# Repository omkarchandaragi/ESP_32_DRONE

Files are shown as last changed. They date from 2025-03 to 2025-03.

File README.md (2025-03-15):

# ESP_32_DRONE
WIFI Controlled Drone
Features of our DIY WiFi-Controlled Drone:
✅WiFi controlled: This can be controlled using a smartphone.
✅MPU6050 IMU for stability control.
✅All-in-one PCB:  Doesn’t need any 3D printed parts or such.
✅Easily upgradable: Additional features such as position hold or height hold can be added using external modules.
✅Small size and lightweight.
✅Built-in battery charger.
✅Built-in USB interface for programming and debugging.
✅Android and IOS apps.
✅Open source

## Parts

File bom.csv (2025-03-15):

Designator | Footprint | Quantity | Value | LCSC Part #
C1, C4 | 603 | 2 | 10u
C10, C15, C16, C17, C18, C8 | 603 | 6 | 1uf
C11, C12, C13, C6 | 603 | 4 | 0.1uf
C14, C5, C7, C9 | 603 | 4 | 10uf
C2 | 603 | 1 | 470pF
C3 | 805 | 1 | 2.2uF
D1 | D_SMA | 1 | SS34
D2, D3, D4, D5 | D_SOD-323 | 4 | 1N4148W
IC1 | SOIC127P600X175-9N | 1 | TP4056
J1 | USB_C_Receptacle_HRO_TYPE-C-31-M-12 | 1 | USB_C_Receptacle_USB2.0
J2, J4, J5, J6 | JST_GH_SM02B-GHS-TB_1x02-1MP_P1.25mm_Horizontal | 4 | Conn_01x02_Female
J3 | JST_PH_B2B-PH-SM4-TB_1x02-1MP_P2.00mm_Vertical | 1 | B2B-PH-SM4-TB(LF)(SN)
J8, J9 | PinHeader_1x06_P2.54mm_Vertical | 2 | Conn_01x06_Female
LED1 | 603 | 1 | POW_LED
LED2, LED3 | 603 | 2 | CHG
LED4, LED5, LED6 | 603 | 3 | LED
R1 | 603 | 1 | 470R
R10, R11, R12, R14, R18, R19, R20, R21, R7 | 603 | 9 | 10k
R13 | 603 | 1 | 4.7k
R15, R16, R17, R8, R9 | 603 | 5 | 1K
R2, U1, U4, U5 | 603 | 4 | 100K
R3, R4 | 603 | 2 | 1.3K
R5 | 603 | 1 | 47.5k
R6 | 603 | 1 | 22.1k
Rprog1 | 603 | 1 | 3.3K
SW1 | slide switch spdt | 1 | K3-1280S-F1
T1, T2, T3, T4 | SOT95P237X112-3N | 4 | SI2302DS-T1
U2 | SOT-23 | 1 | AO3401
U3 | SOT-23-5 | 1 | MIC5219-3.3YM5
U6 | QFN-28-1EP_5x5mm_P0.5mm_EP3.35x3.35mm | 1 | CP2102N-Axx-xQFN28
U7 | SOT-363_SC-70-6 | 1 | 2N7002D
U8 | ESP32-WROOM-32 | 1 | ESP32-WROOM-32
U9 | MPU6050 | 1 | MPU-6050

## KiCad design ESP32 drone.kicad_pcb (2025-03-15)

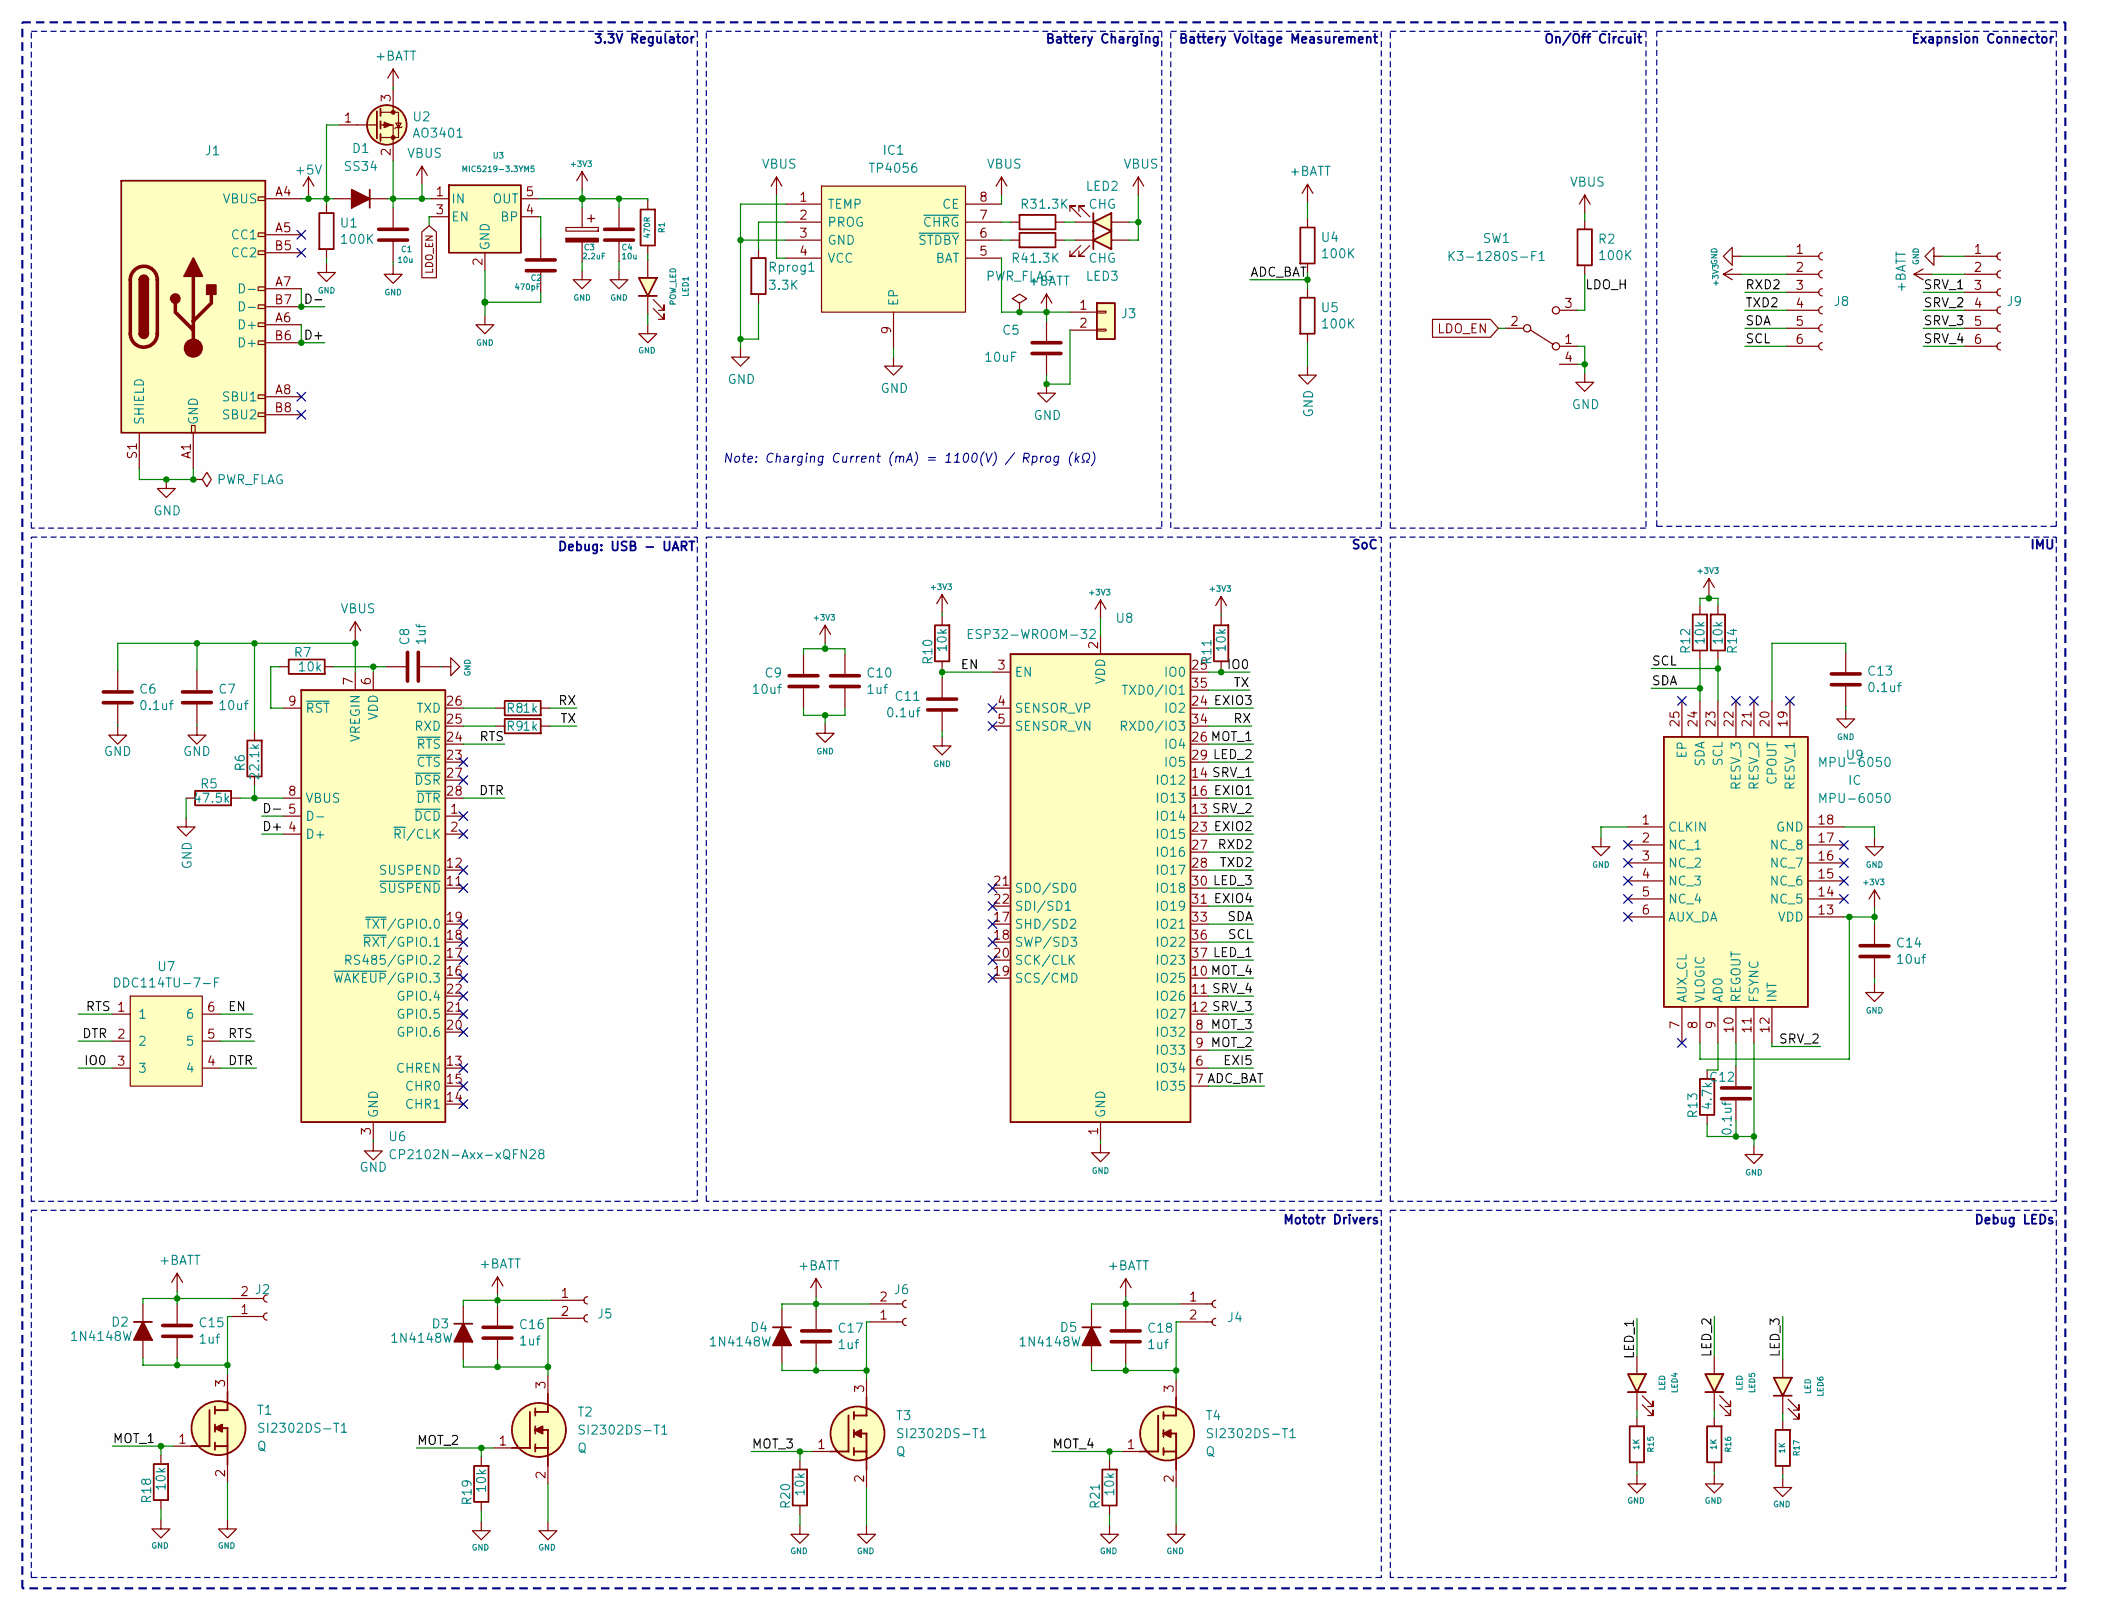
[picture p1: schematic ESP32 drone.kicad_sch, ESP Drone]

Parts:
C1, C4: 10u; C_0603_1608Metric
C2: 470pF; C_0603_1608Metric
C3: 2.2uF; C_0805_2012Metric
C5: 10uF; C_0603_1608Metric
C6, C11, C12, C13: 0.1uf; C_0603_1608Metric
C7, C9, C14: 10uf; C_0603_1608Metric
C8, C10, C15, C16, C17, C18: 1uf; C_0603_1608Metric
D1: SS34; D_SMA
D2, D3, D4, D5: 1N4148W; D_SOD-323
IC1: TP4056; SOIC127P600X175-9N; Manufacturer_Part_Number TP4056-42-ESOP8
J1: USB_C_Receptacle_USB2.0; USB_C_Receptacle_HRO_TYPE-C-31-M-12
J2, J4, J5, J6: Conn_01x02_Female; JST_GH_SM02B-GHS-TB_1x02-1MP_P1.25mm_Horizontal
J3: B2B-PH-SM4-TB(LF)(SN); JST_PH_B2B-PH-SM4-TB_1x02-1MP_P2.00mm_Vertical
J8, J9: Conn_01x06_Female; PinHeader_1x06_P2.54mm_Vertical
LED1: POW_LED; LED_0603_1608Metric
LED2, LED3: CHG; LED_0603_1608Metric
LED4, LED5, LED6: LED; LED_0603_1608Metric
R1: 470R; R_0603_1608Metric
R2: 100K; R_0603_1608Metric
R3, R4: 1.3K; R_0603_1608Metric
R5: 47.5k; R_0603_1608Metric
R6: 22.1k; R_0603_1608Metric
R7, R10, R11, R12, R14, R18, R19, R20, R21: 10k; R_0603_1608Metric
R8, R9: 1k; R_0603_1608Metric
R13: 4.7k; R_0603_1608Metric
R15, R16, R17: 1K; R_0603_1608Metric
Rprog1: 3.3K; R_0603_1608Metric
SW1: K3-1280S-F1; slide switch spdt
T1, T2, T3, T4: SI2302DS-T1; SOT95P237X112-3N; Mouser Part Number 781-SI2302DS
U1, U4, U5: 100K; R_0603_1608Metric
U2: AO3401; SOT-23
U3: MIC5219-3.3YM5; SOT-23-5
U6: CP2102N-Axx-xQFN28; QFN-28-1EP_5x5mm_P0.5mm_EP3.35x3.35mm
U7: DDC114TU-7-F; SOT-363_SC-70-6
U8: ESP32-WROOM-32
U9: MPU-6050; MPU6050; Mouser Part Number 410-MPU-6050

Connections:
+3V3: C3.1, C4.1, C9.1, C10.1, C14.1, J8.2, R1.2, R10.2, R11.2, R12.2, R14.2, U3.5 (OUT), U8.2 (VDD), U9.8 (VLOGIC), U9.13 (VDD)
+5V: D1.2 (A), J1.A4 (VBUS), J1.A9 (VBUS), J1.B4 (VBUS), J1.B9 (VBUS), U1.1, U2.1 (G)
+BATT: C5.1, C15.1, C16.1, C17.1, C18.1, D2.1 (K), D3.1 (K), D4.1 (K), D5.1 (K), IC1.5 (BAT), J2.2, J3.1, J4.1, J5.1, J6.2, J9.2, U2.3 (D), U4.1
/ADC_BAT: U4.2, U5.1, U8.7 (IO35)
/D+: J1.A6 (D+), J1.B6 (D+), U6.4 (D+)
/D-: J1.A7 (D-), J1.B7 (D-), U6.5 (D-)
/DTR: U6.28 (~DTR), U7.2, U7.4
/EN: C11.1, R10.1, U7.6, U8.3 (EN)
/EXI5: U8.6 (IO34)
/EXIO1: U8.16 (IO13)
/EXIO2: U8.23 (IO15)
/EXIO3: U8.24 (IO2)
/EXIO4: U8.31 (IO19)
/IO0: R11.1, U7.3, U8.25 (IO0)
/LDO_H: R2.2, SW1.3 (C)
/LED_1: LED4.2 (A), U8.37 (IO23)
/LED_2: LED5.2 (A), U8.29 (IO5)
/LED_3: LED6.2 (A), U8.30 (IO18)
/MOT_1: R18.2, T1.1 (G), U8.26 (IO4)
/MOT_2: R19.2, T2.1 (G), U8.9 (IO33)
/MOT_3: R20.2, T3.1 (G), U8.8 (IO32)
/MOT_4: R21.2, T4.1 (G), U8.10 (IO25)
/RTS: U6.24 (~RTS), U7.1, U7.5
/RX: R8.2, U8.34 (RXD0/IO3)
/RXD2: J8.3, U8.27 (IO16)
/SCL: J8.6, R14.1, U8.36 (IO22), U9.23 (SCL)
/SDA: J8.5, R12.1, U8.33 (IO21), U9.24 (SDA)
/SRV_1: J9.3, U8.14 (IO12)
/SRV_2: J9.4, U8.13 (IO14), U9.12 (INT)
/SRV_3: J9.5, U8.12 (IO27)
/SRV_4: J9.6, U8.11 (IO26)
/TX: R9.2, U8.35 (TXD0/IO1)
/TXD2: J8.4, U8.28 (IO17)
GND: C1.2, C2.2, C3.2, C4.2, C5.2, C6.2, C7.2, C8.2, C9.2, C10.2, C11.2, C12.2, C13.2, C14.2, IC1.1 (TEMP), IC1.3 (GND), IC1.9 (EP), J1.A1 (GND), J1.A12 (GND), J1.B1 (GND), J1.B12 (GND), J1.S1 (SHIELD), J3.2, J8.1, J9.1, LED1.1 (K), R5.1, R13.1, R15.1, R16.1, R17.1, R18.1, R19.1, R20.1, R21.1, Rprog1.2, SW1.1 (A), SW1.4, T1.2 (S), T2.2 (S), T3.2 (S), T4.2 (S), U1.2, U3.2 (GND), U5.2, U6.3 (GND), U6.29 (GND), U8.1 (GND), U8.15 (GND), U8.38 (GND), U8.39 (GND), U9.1 (CLKIN), U9.11 (FSYNC), U9.18 (GND)
LDO_EN: SW1.2 (B), U3.3 (EN)
unnamed: C15.2, D2.2 (A), J2.1, T1.3 (D)
unnamed: C16.2, D3.2 (A), J5.2, T2.3 (D)
unnamed: C17.2, D4.2 (A), J6.1, T3.3 (D)
unnamed: C18.2, D5.2 (A), J4.2, T4.3 (D)
unnamed: IC1.2 (PROG), Rprog1.1
unnamed: IC1.7 (~CHRG), R3.2
unnamed: IC1.6 (~STDBY), R4.2
unnamed: LED1.2 (A), R1.1
unnamed: LED2.1 (K), R3.1
unnamed: LED3.1 (K), R4.1
unnamed: LED4.1 (K), R15.2
unnamed: LED5.1 (K), R16.2
unnamed: LED6.1 (K), R17.2
unnamed: C2.1, U3.4 (BP)
unnamed: R9.1, U6.25 (RXD)
unnamed: R8.1, U6.26 (TXD)
unnamed: R5.2, R6.1, U6.8 (VBUS)
unnamed: C8.1, R7.2, U6.6 (VDD)
unnamed: R7.1, U6.9 (~RST)
unnamed: R13.2, U9.9 (AD0)
unnamed: C13.1, U9.20 (CPOUT)
unnamed: C12.1, U9.10 (REGOUT)
VBUS: C1.1, C6.1, C7.1, D1.1 (K), IC1.4 (VCC), IC1.8 (CE), LED2.2 (A), LED3.2 (A), R2.1, R6.2, U2.2 (S), U3.1 (IN), U6.7 (VREGIN)

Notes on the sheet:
SoC
Battery Voltage Measurement
IMU
Mototr Drivers
Battery Charging
Debug LEDs
Debug: USB - UART
Exapnsion Connector
3.3V Regulator
Note: Charging Current (mA) = 1100(V) / Rprog (kΩ)
On/Off Circuit

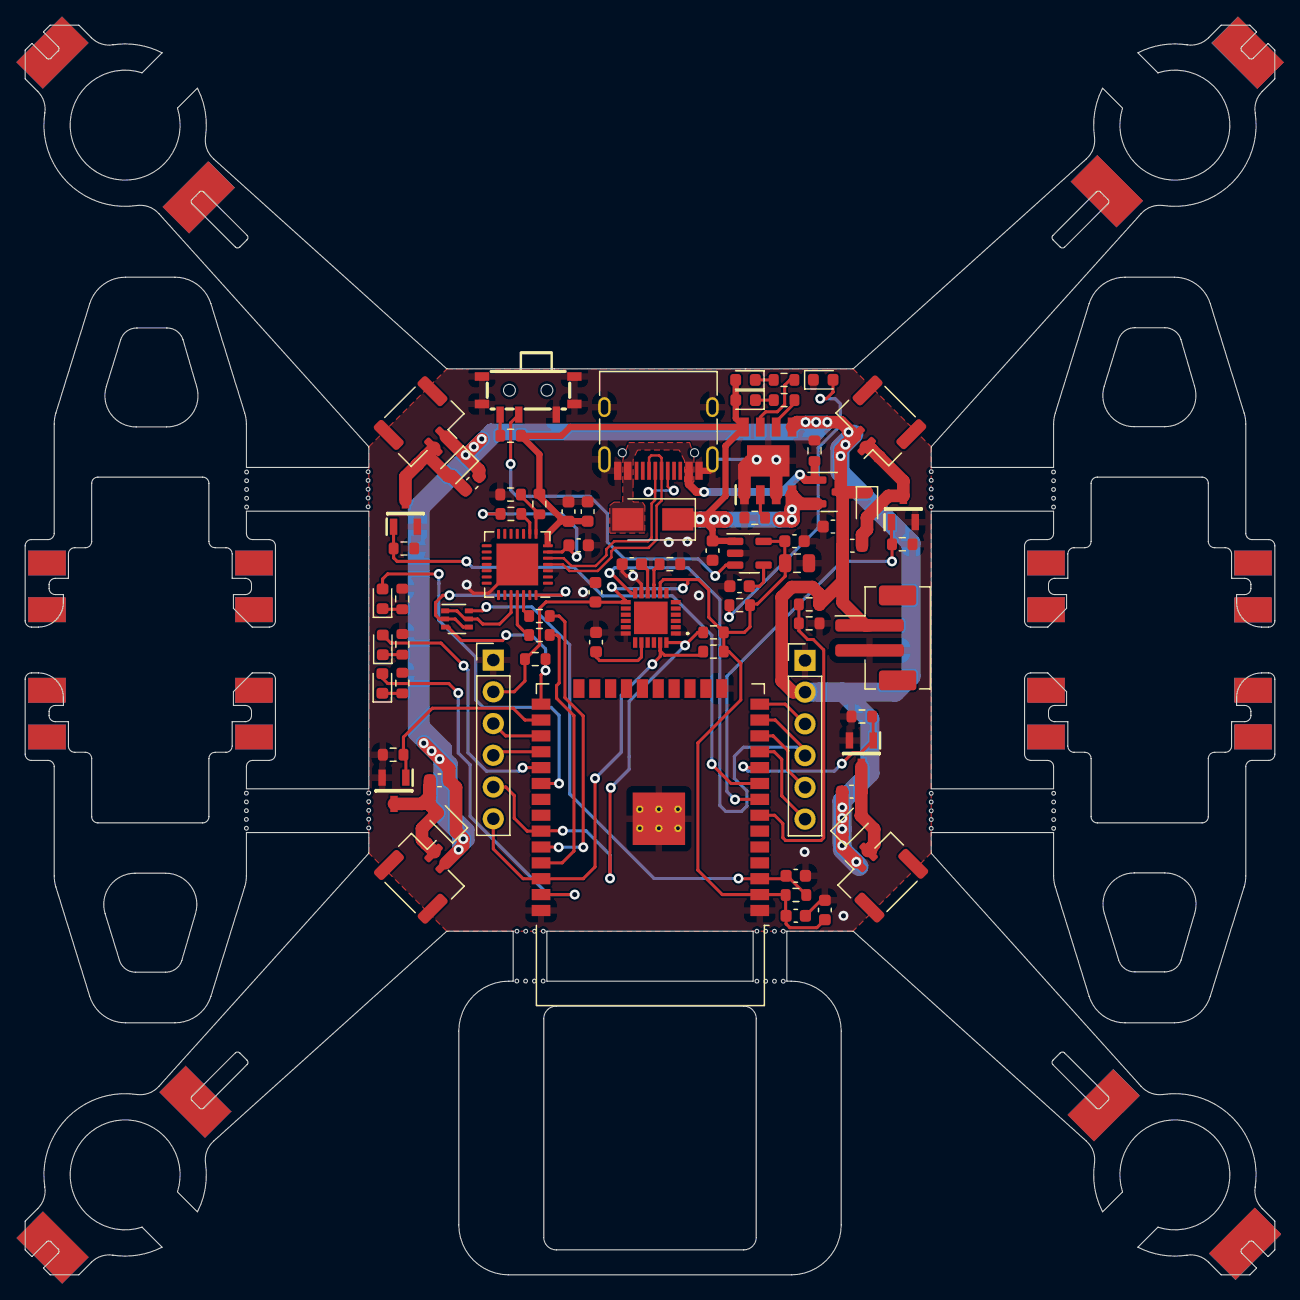
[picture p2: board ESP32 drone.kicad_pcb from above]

Board: 2 copper layers, 100.0 x 100.0 mm, 74 parts (0 on the bottom side), 53 nets.
